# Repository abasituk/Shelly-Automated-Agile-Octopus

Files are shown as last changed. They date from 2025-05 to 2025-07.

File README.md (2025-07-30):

# Shelly-Automated-Agile-Octopus
A system used to automate a Shelly relay to switch on during the cheapest period of the Agile Octopus tariff.

System Diagram (1)

The software requires a Python capable device with WiFi. A Raspberry Pi 4B is used for the build tutorial, with alterantives including cheaper models, such as the Pi Zero 2 W.

## System Functions
- Calculates the cheapest period of electricity prices per day.
- Switches on a Shelly relay through the cloud during the cheapest period, then switches it off outside of that period.
- Hosts a webpage which runs on the local network to display Agile Octopus' half-hourly prices and control the system.

# Hardware List

The relay subsystem may use a Shelly relay when installed into an existing socket or a Shelly Plus plug for portability.

### 1a. BOM for the IoT-based system (Configuration 1).

| Identifier | Component | Quantity | Component Cost [GBP] | Source |
|---|---|---|---|---|
| SBC | Raspberry Pi Zero 2W | 1 | £16.98 | ThePiHut |
| Display | 0.96" OLED Display Module | 1 | £4.00 | ThePiHut |
| SBC Power | Raspberry Pi 12.5W Power Supply | 1 | £7.50 | ThePiHut |
| Smart Relay | Shelly 1PM Gen3 | 1 | £18.50 | ThePiHut |

### 1b. Alternative BOM for the IoT-based system, utilising a smart plug (Configuration 2).

| Identifier | Component | Quantity | Component Cost [GBP] | Source |
|---|---|---|---|---|
| SBC | Raspberry Pi Zero 2W | 1 | £16.98 | ThePiHut |
| Display | 0.96" OLED Display Module | 1 | £4.00 | ThePiHut |
| SBC Power | Raspberry Pi 12.5W Power Supply | 1 | £7.50 | ThePiHut |
| Smart Relay | Shelly Plus Plug | 1 | £18.50 | ThePiHut |

### 3. Additional components used for the control subsystems assembly.

Count|Power/Connectors|
-----|----------------|
1|Rapsberry Pi 15W USB-C Power Supply|
1|14 AWG or 2.5mm<sup>2</sup> Wire|
4|Jumper Wires|
4|M3 x 8 Bolts|
4|M3 Nuts
4|M2 x 6 Bolts|
4|M2 Nuts

If the Shelly Plus plug is be unavailable for purchase, the Shelly relay can be utilised in a customised portable relay subsystem.
### 4. Optional components used to build a portable relay subsystem with the Shelly Relay.

Count|Component
--|--
1|C14 Panel Mount IEC Connector Male
1|IEC C13 Socket to Type G UK Plug Power Cord
1|UK Switched Electrical Socket (2 poles)
6|M3 x 8 length Bolts
6|M3 Nuts
2|M4 Screws
2|M4 Nuts
3|Spade/quick disconnect connectors

# Hardware Build Guide

This section describes how to build two subsystems:
- The Control Subsystem:
  - Consisting of the Raspberry Pi and display, it calculates the cheapest period of energy prices and controls the relay.
- The Relay Subsystem:
  - A circuit which utilises a relay to power an appliance as requested by the control subsystem.

## Control Subsystem Build Guide

### Control Subsystem Printing List

| Count | Model |
|---|---|
| 1 | Pi Zero 2W Enclosure With Screen.stl |
| 2 | Pi Zero 2W Enclosure With Screen Cap.stl |

1. The display is connected to the Raspberry Pi with jumper wires.

|Display|Raspberry Pi Pin|Raspberry Pi Pin Name|
|-|-|-|
SDA|3|GPIO2
SCL|5|GPIO3
VCC|1|3V3
GND|9|GND

2. The Raspberry Pi and display are mounted to the floor of the enclosure with 4 M3 bolts and M2 bolts.



3. The enclosure is folded along its live hinges.

4. Endcaps are press-fitted to both ends.

## Relay Subsystem Build Guide

*Outlines the installation of the Shelly relay into an electrical socket*

1. The Shelly 1PM gen3 is wired according to the diagram:





An animation displays this process, where power is delivered through an IEC connector.

<details>
  <summary>Individual Relay Wiring Images</summary>
  image-description
  image-description
  image-description
  image-description
  image-description
  image-description
  image-description
</details>

# installation guide

## Raspberry Pi Setup

1. Using [Raspberry Pi Imager](https://www.raspberrypi.com/software/), select the utilised Raspberry Pi model, Raspberry Pi OS (64 bit) and your microSD card, then press next

2. On the dialogue that appears, edit the custom OS settings to allow your Pi to connect to your WiFi

3. Type in a username and password for your Pi, then your WiFi name and password

4. Save and apply the settings, then write to your microSD card

5. SSH into the Pi.

## System Installation

1. Download install.sh
```
wget https://raw.githubusercontent.com/abasituk/Shelly-Automated-Agile-Octopus/main/Install.sh
```

2. Give it permission to run
```
chmod +x Install.sh
```

3. Run it with sudo, the script will download the scripts, services and requirements
```
sudo ./Install.sh
```

<br/>

4. After the installation is finished, enable your I2c Interface by first opening your config

  4a. Open your Pi's config
```
sudo raspi-config
```

4b. Open 'Interface Options'

4c. Select 'I2C'

4d. Enable the I2C interface

<br/>
5. Add your Shelly and tariff details to the system's config.ini file
5a. Navigate to where the system was installed

```
cd /home/pi/shelly
```

5b. Open config.ini
```
nano config.ini
```

5c. Add your Shelly and tariff details to the config.ini file without the comments:
```
[Shelly_Variables]                         # Available at https://control.shelly.cloud/
DEVICE_ID = X                                  # device settings -> Device information
SERVER_URI = shelly-X-eu.shelly.cloud          # account settings -> Authorization cloud key (note: not including https://)
AUTH_KEY = X                                   # account settings -> Authorization cloud key

[Tariff_Details]                       # Details for your agile octopus tariff (to interact with the API)
region_code = B                          # Region code for east midlands (e.g. Lincolnshire)
product_code = AGILE-24-10-01            # Your agile octopus tariff's product code
electricity_tariff_type = E-1R           # As Agile Octopus prices change based on wholesale prices, this probably won't need changing
period_size = 1                          # How long you would like your appliance to be switched on (1 period = 0.5 hours)

[Timing_Variables]                     # How quickly the code will loop
INTERVAL = 2                             # Determines how quickly the webgraph updates, increase the value if your Pi is struggling
```

5d. Once the details have been added, press `Ctrl+X`, then `Y`, then `Enter` to save and exit the config.ini file.

<br/>

6. Reload Systemd
```
sudo systemctl daemon-reload
```

7. Restart your services
```
sudo systemctl restart shellycontrol.service webgraph.service
```

<br/>

After these steps, type `http://'Your Pi's IP Address':8080` into a browser on the same WiFi network to access the system's webgraph.

You can also check the status of the services to see if there are any errors:
```
systemctl status shellycontrol.service
```
and
```
systemctl status webgraph.service
```

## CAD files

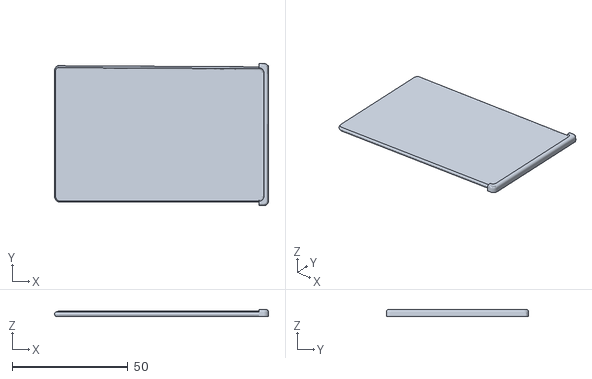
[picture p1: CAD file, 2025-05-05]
Enclosures/Control Subsystem/Raspberry Pi 4B/Raspberry Pi 4B Enclosure Lid 2A.stl
92.5 x 61.5 x 3.00

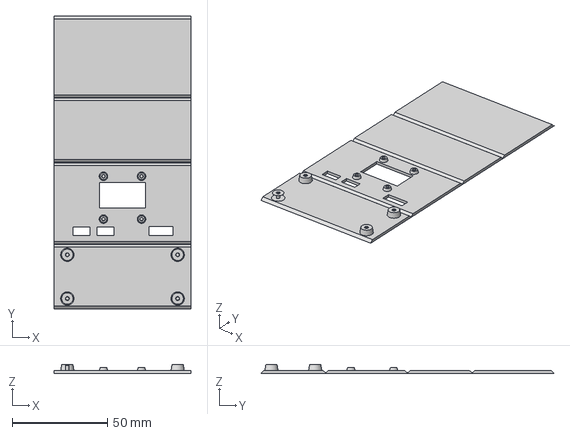
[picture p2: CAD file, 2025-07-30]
Enclosures/Control Subsystem/Raspberry Pi Zero 2W/Pi Zero 2W Enclosure With Screen 14b.step
72.0 x 154.0 x 4.50 mm

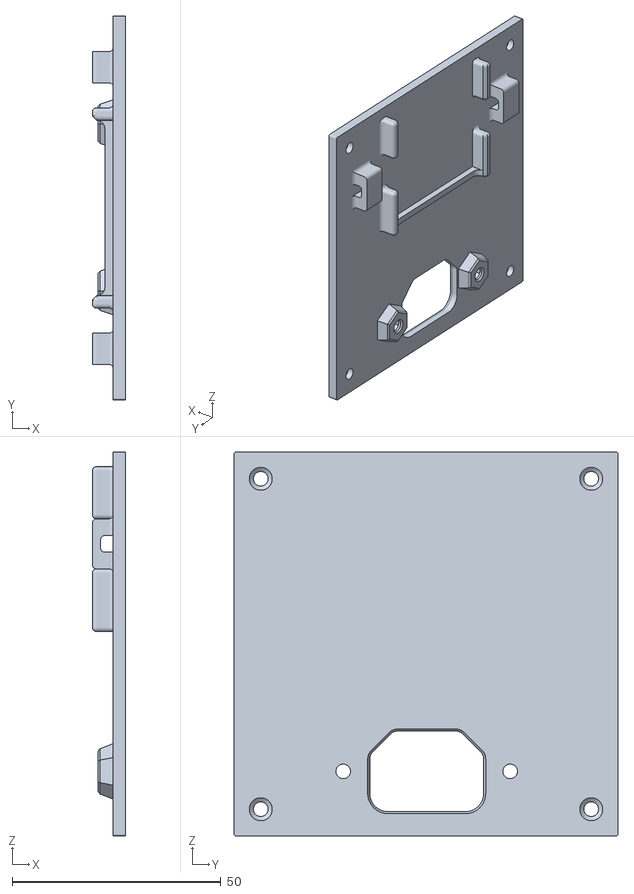
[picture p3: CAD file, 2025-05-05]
Enclosures/Relay Subsystem/Relay Box 2D6 Lid.stl
8.00 x 92.0 x 92.0

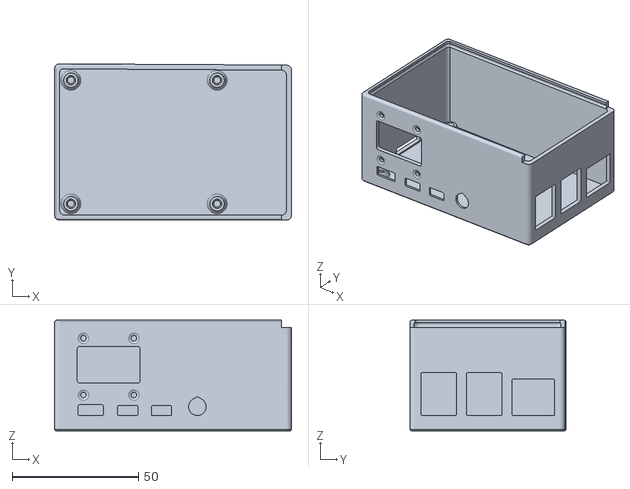
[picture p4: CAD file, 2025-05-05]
Enclosures/Control Subsystem/Raspberry Pi 4B/Raspberry Pi 4B Enclosure 2B.stl
94.0 x 62.0 x 44.0

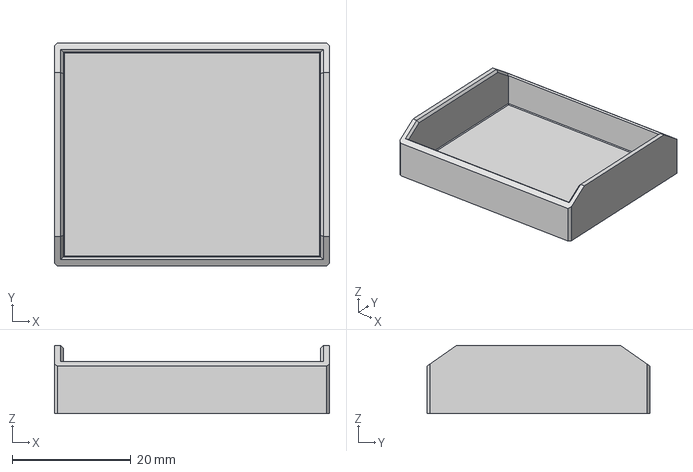
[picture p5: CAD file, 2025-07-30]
Enclosures/Control Subsystem/Raspberry Pi Zero 2W/Pi Zero 2W Enclosure With Screen 14b Cap.step
46.3 x 37.6 x 11.5 mm

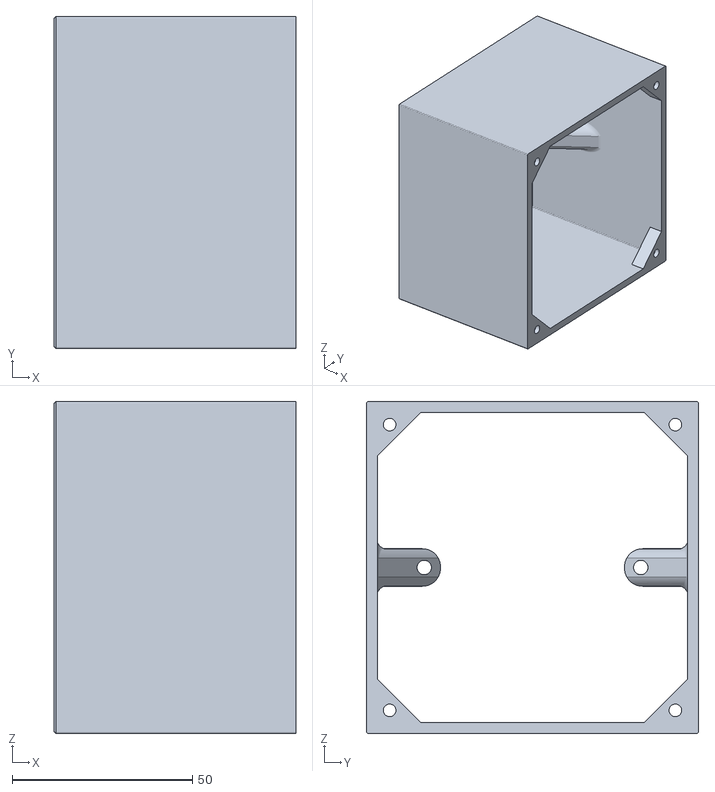
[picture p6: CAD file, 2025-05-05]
Enclosures/Relay Subsystem/Relay Box 2D4.stl
67.0 x 92.0 x 92.0

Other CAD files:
Enclosures/Control Subsystem/Raspberry Pi Zero 2W/Pi Zero 2W Enclosure With Screen 14a.stl
Enclosures/Control Subsystem/Raspberry Pi Zero 2W/Pi Zero 2W Enclosure With Screen 14b Cap.stl

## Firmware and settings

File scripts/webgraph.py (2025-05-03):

import requests
import plotly.graph_objects as go
from plotly.io import to_json
import pandas as pd
from flask import Flask, render_template, request, redirect, url_for, jsonify
from datetime import datetime, timedelta, date, timezone
import time
from threading import Thread
import tzlocal
import os
import configparser

app = Flask(__name__, template_folder=".")

# get the local timezone
local_tz = tzlocal.get_localzone()

# config variables to seperate changeable variables from code ==================================
config = configparser.ConfigParser()
config_file_path = os.path.join(os.path.dirname(__file__), '..', 'config.ini')

try:
    config.read(config_file_path)
except Exception as e:
    print(f"Error reading config.ini file: {e}")
    exit(1)


DEVICE_ID = config.get('Shelly_Variables', 'DEVICE_ID')
SERVER_URI = config.get('Shelly_Variables', 'SERVER_URI')
AUTH_KEY = config.get('Shelly_Variables', 'AUTH_KEY')

region_code = config.get('Tariff_Details', 'region_code')
product_code = config.get('Tariff_Details', 'product_code')
electricity_tariff_type = config.get('Tariff_Details', 'electricity_tariff_type')
period_size = config.getint('Tariff_Details', 'period_size')

INTERVAL = config.getint('Timing_Variables', 'INTERVAL')
# config variables end ========================================================================

automatic_mode = True
start_time_global = None
end_time_global = None


# Optimal Period calc ===============================================================
def retrieve_energy_data_from_api(target_date):
    tomorrow = target_date + timedelta(days=1)
    day_start = datetime.combine(target_date, datetime.min.time(), tzinfo=local_tz).astimezone(timezone.utc).strftime("%Y-%m-%dT%H:%M:%SZ")
    day_end = datetime.combine(tomorrow, datetime.min.time(), tzinfo=local_tz).astimezone(timezone.utc).strftime("%Y-%m-%dT%H:%M:%SZ")

    tariff_code = f"{electricity_tariff_type}-{product_code}-{region_code}"
    base_url = f"https://api.octopus.energy/v1/products/{product_code}/electricity-tariffs/{tariff_code}/standard-unit-rates/"
    params = {"period_from": day_start, "period_to": day_end}
    try:
        response = requests.get(base_url, params=params)
        response.raise_for_status()
        data = response.json()
        results = data.get("results", [])
        if results:
            df = pd.DataFrame(results)
            df["Time Period"] = pd.to_datetime(df["valid_from"]).dt.tz_convert(timezone.utc) # fixed
            df["Price"] = df["value_inc_vat"]
            return df[["Time Period", "Price"]]
        else:
            print(f"Could not find data for {target_date}")
            return None
    except requests.exceptions.RequestException as e:
        print(f"Could not retrieve data from Octopus Energy API: {e}")
        return None

# cycle through the periods to find lowest price
def find_optimal_period(df):
    min_average_price = float("inf")
    optimal_start_index = 0
    
    if df is None or len(df) < period_size:
        return None, None
    for i in range(len(df) - period_size + 1):
        period_average = df["Price"].iloc[i : i + period_size].mean()
        if period_average < min_average_price:
            min_average_price = period_average
            optimal_start_index = i
    return (
        df.iloc[optimal_start_index : optimal_start_index + period_size],
        min_average_price,
    )

# Save the optimal period start and end times, and define what the relay should do during and outside optimal period
def update_optimal_period():
    global start_time_global, end_time_global
    today = date.today()
    df = retrieve_energy_data_from_api(today)

    if df is not None:
        optimal_period_df, average_price = find_optimal_period(
            df.sort_values(by= "Time Period").reset_index(drop=True)
        )
        if optimal_period_df is not None and not optimal_period_df.empty:
            start_time = optimal_period_df["Time Period"].iloc[0]
            end_time = optimal_period_df["Time Period"].iloc[-1] + timedelta(minutes = 30)

            start_time_global = start_time
            end_time_global = end_time

            current_time_utc = datetime.now(timezone.utc)

            if start_time <= current_time_utc < end_time:
                state = switch_relay("on")
                print(f"Relay switched ON for optimal period. Status: {state}")
            else:
                state = switch_relay("off")
                print(f"Relay switched OFF as currently outside optimal period. Status: {state}")
        else:
            print("Could not find optimal period for today")
            switch_relay("off")
            start_time_global = None
            end_time_global = None
    else:
        print("Could not retrieve the energy data for today.")
# ===================================================================================================================================================


# Relay Control =====================================================================================================================================
def relay_status():
    url = f"https://{SERVER_URI}/device/status"
    data = {"id": DEVICE_ID, "auth_key": AUTH_KEY}
    try:
        response = requests.post(url, data = data)
        response.raise_for_status()
        device_data = response.json().get("data", {})
        device_status = device_data.get("device_status", {})
        relay_info = device_status.get("switch:0", {})
        return relay_info.get("output", False)
    except requests.exceptions.RequestException as e:
        print(f"Error checking relay status: {e}")
        return False

# communicate with the shelly relay over cloud
def switch_relay(turn_state):
    url = f"https://{SERVER_URI}/device/relay/control"
    data = {"channel": 0, "turn": turn_state, "id": DEVICE_ID, "auth_key": AUTH_KEY}
    try:
        response = requests.post(url, data=data)
        response.raise_for_status()
        return response.json()
    except requests.exceptions.RequestException as e:
        print(f"Error when trying to control the relay: {e}")
        return {"error": str(e)}


# code to host the webpage locally, which will allow controlling the iot system from PCs, phones etc. on the local network ==================
@app.route("/")
# make a graph for the webpage to visually show the energy prices
def display_graph():
    global start_time_global, end_time_global
    today = date.today()
    df = retrieve_energy_data_from_api(today)

    graph_json = "{}"
    error_message = None

    if df is not None:
        df_sorted = df.sort_values(by="Time Period").reset_index(drop=True)
        optimal_period_df, average_price = find_optimal_period(df_sorted.copy())

        start_time_utc = None
        end_time_utc = None

        if optimal_period_df is not None and not optimal_period_df.empty:
            start_time_utc = optimal_period_df["Time Period"].iloc[0]
            end_time_utc = optimal_period_df["Time Period"].iloc[-1] + timedelta(minutes=30)
            start_time_global = start_time_utc
            end_time_global = end_time_utc
        else:
             if start_time_global and start_time_global.date() == start_time_utc.astimezone(local_tz).date():
                 start_time_global = None
                 end_time_global = None
             average_price = None


        fig = go.Figure()

        df_sorted["Time Period Local"] = df_sorted["Time Period"].dt.tz_convert(local_tz)

        fig.add_trace(
            go.Bar(
                x=df_sorted["Time Period Local"].dt.strftime("%H:%M"),
                y=df_sorted["Price"],
                hovertemplate="Time: %{x}<br>Price: %{y:.2f} p/kWh",
                marker=dict(color=df_sorted["Price"], coloraxis="coloraxis"),
                name="",
            )
        )

        if start_time_utc and end_time_utc and average_price is not None:
            start_time_local_display = start_time_utc.astimezone(local_tz)
            end_time_local_display = end_time_utc.astimezone(local_tz)

            period_duration_minutes = period_size * 30
            if period_duration_minutes >= 60 and period_duration_minutes % 60 == 0:
                duration_text = f"{period_duration_minutes // 60}-Hour"
            else:
                duration_text = f"{period_duration_minutes}-Minute"


            fig.add_annotation(
                x = start_time_local_display.strftime("%H:%M"),
                y = df_sorted["Price"].max() * 1.1 if not df_sorted.empty else 1,
                text = (
                    f"Optimal {duration_text} period: {start_time_local_display.strftime('%H:%M')} - {end_time_local_display.strftime('%H:%M')}<br>"
                    f"Average Price: {average_price:.2f} p/kWh" # 2 decimal places
                ),
                showarrow = False,
                bgcolor = "yellow",
                font = dict(size=16),
            )
        # bug fix 2
        try:
            tz_name = local_tz.key
        except AttributeError:
            tz_name = str(local_tz)

        fig.update_layout(
            xaxis_title=f"Time Period ({tz_name})",
            yaxis_title="Price (p/kWh)",
            coloraxis = dict(colorbar=dict(title="Price (p/kWh)")),
            autosize = True,
        )

        graph_json = to_json(fig)
    else:
        error_message="Could not retrieve energy data."

    # use the webpage
    return render_template(
        "webpage.html",
        graph_json = graph_json,
        interval = INTERVAL,
        automaticMode = automatic_mode,
        error = error_message
    )



@app.route("/status")
# Set what the relay status should be
# 2c 
def get_relay_status():
    global start_time_global, end_time_global
    current_status = relay_status()
    display_relay_status = "ON" if current_status else "OFF"
    auto_mode_status = "ON" if automatic_mode else "OFF"

    current_time_utc = datetime.now(timezone.utc)

    optimal_period_display = "Calculating Optimal Period"
    currently_optimal = "False"

    if start_time_global and end_time_global:
        if start_time_global.astimezone(local_tz).date() == current_time_utc.astimezone(local_tz).date():
            start_time_local_display = start_time_global.astimezone(local_tz)
            end_time_local_display = end_time_global.astimezone(local_tz)
            try:
                tz_name = local_tz.key
            except AttributeError:
                tz_name = str(local_tz)
            optimal_period_display = f"{start_time_local_display.strftime('%H:%M')} - {end_time_local_display.strftime('%H:%M')} ({tz_name})"

            if start_time_global <= current_time_utc < end_time_global:
                 currently_optimal = "True"
            else:
                 currently_optimal = "False"
        else:
             optimal_period_display = "Waiting for today's data"
             currently_optimal = "False"
    else:
        optimal_period_display = "Optimal period data is unavailable"
        currently_optimal = "False"

    return jsonify(
        optimalPeriod=optimal_period_display,
        currentlyOptimal=currently_optimal,
        autoModeStatus=auto_mode_status,
        relayStatus=display_relay_status,
    )

# Webpage buttons ================================
@app.route("/switch_relay", methods=["POST"])
def switch_relay_route():
    turn_state = request.form["turnState"]
    switch_relay(turn_state)
    return redirect(url_for("display_graph"))


@app.route("/toggle_auto_mode", methods=["POST"])
def toggle_auto_mode():
    global automatic_mode
    automatic_mode = not automatic_mode
    return redirect(url_for("display_graph"))


def run_automatic_mode():
    while True:
        if automatic_mode:
            update_optimal_period()
        time.sleep(INTERVAL)
# ===================================================

automatic_thread = Thread(target = run_automatic_mode)
automatic_thread.daemon = True
automatic_thread.start()

if __name__ == "__main__":
    try:
        tz_name = local_tz.key
    except AttributeError:
        tz_name = str(local_tz)
    print(f"Found local timezone: {tz_name}")
    print("Starting Webpage")
    app.run(host = "0.0.0.0", port=8080, debug=False) # run it locally

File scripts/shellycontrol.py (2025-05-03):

import requests
import time
import board
import busio
from PIL import Image, ImageDraw, ImageFont
from adafruit_ssd1306 import SSD1306_I2C
from datetime import datetime

# Variables =======================================================================================
# Typed in camelCase just for ease of distinguishing them in the code
interval = 0.1 # How quick the script is looped
webpageURL = "http://localhost:8080" # this is localhost as the webpage is hosted on the same device

# Set up the OLED screen by setting the pins used
# adafruit_ssd1306 is used because it is compatible with the OLED display
pins = busio.I2C(board.SCL, board.SDA)
oled = SSD1306_I2C(128, 64, pins)

# Set up the display to not have to refresh fully to display something new,
# instead only the pixels that change need to be refreshed, 
# this reduces the screen flashing on and off
previous_display = {
    "optimal_period": "",
    "currently_optimal": "",
    "auto_mode": "",
    "relay_status": ""
}



# Functions =======================================================================================
# Gets information about the 
# optimal period and relay from the webpage so it can be displayed on the webgraph and OLED screen
def get_all_info():
    try:
        response = requests.get(f"{webpageURL}/status")
        response.raise_for_status()
        return response.json()
    except requests.RequestException as e:
        print("Error when retrieving status:", e)
        return None

def update_oled_display(optimal_start, optimal_end, is_currently_optimal, auto_mode_status, relay_status):

    image = Image.new('1', (oled.width, oled.height)) # The display first is set up with an empty image
    draw = ImageDraw.Draw(image)
    font = ImageFont.load_default()

    date = time.strftime("%H:%M   %d/%m/%y")

    # Setting up texts that will be displayed on the OLED, the text changes based on the information,
    new_display = {
        # text name : text then info variables e.g. Auto Mode: true
        "title_text": f"{date}",
        "optimal_period": "Optimal Period:",
        "optimal_period_2": f"{optimal_start} - {optimal_end}",
        "currently_optimal": "Currently Optimal: " + ("True" if is_currently_optimal else "False"),
        "auto_mode": "Auto Mode: " + ("On" if (auto_mode_status == "ON" or auto_mode_status is True) else "Off"),
        "relay_status": "Relay Status: " + ("On" if (relay_status == "ON" or relay_status is True) else "Off")
    }

    # the display is set blank, then the pixels of the text are set on
    draw.rectangle((0, 0, oled.width, oled.height), outline=0, fill=0)
    draw.text((0, 0), new_display["title_text"], font=font, fill=255) #new
    draw.text((0, 14), new_display["optimal_period"], font=font, fill=255) # Starts at 14 because pixels above are yellow for the OLED display
    draw.text((0, 24), new_display["optimal_period_2"], font=font, fill=255)
    draw.text((0, 34), new_display["currently_optimal"], font=font, fill=255)
    draw.text((0, 44), new_display["auto_mode"], font=font, fill=255)
    draw.text((0, 54), new_display["relay_status"], font=font, fill=255)

    oled.image(image)
    oled.show()
    # Now updates the display based on what changed from the previous display to reduce whole screen flashing
    previous_display.update(new_display)



# Makes the code loop based on an interval, as the display's response time is not significantly impacting the responsiveness of the system
while True:
    status = get_all_info()
    if status is not None: # This makes the display update only if the info is available
        optimal_period = status.get("optimalPeriod", "N/A")
        if optimal_period != "Data Unavailable" and " - " in optimal_period:
            optimal_start, optimal_end = optimal_period.split(" - ")
        else:
            optimal_start, optimal_end = "N/A", "N/A"

        # Changes the currently optimal field to bools to be used in update_oled_display()
        currently_optimal_str = status.get("currentlyOptimal", "False")
        is_currently_optimal = True if currently_optimal_str.lower() == "true" else False

        # Get auto mode and relay (Shelly switch) statuses.
        auto_mode_status = status.get("autoModeStatus", "OFF")
        relay_status = status.get("relayStatus", "OFF")

        # Update the OLED display with the latest information.
        update_oled_display(optimal_start, optimal_end, is_currently_optimal, auto_mode_status, relay_status)
    else:
        print("Could not retrieve information from the server") # For logging issues

    time.sleep(interval)

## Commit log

2025-05-05 Rename Enclosures/Relay Box 2D4.stl to Enclosures/Relay Subsystem/Relay Box 2D4.stl
    [Relay Box 2D4.stl]
2025-05-05 Rename Enclosures/Relay Box 2D6 Lid.stl to Enclosures/Relay Subsystem/Relay Enclosure Lid.stl
    [Relay Enclosure Lid.stl]
2025-05-05 Rename Relay Box 2D4.stl to Relay Enclosure.stl
    [Relay Enclosure.stl]
2025-05-05 Create Relay Subsystem
2025-07-30 Rename Pi Zero 2W Enclosure With Screen 14b Cap.stl to Pi Zero 2W Enclosure With Screen 14b Cap.stl
    [Pi Zero 2W Enclosure With Screen 14b Cap.stl]
2025-07-30 added step files for rpiz2w enclosures
    [Pi Zero 2W Enclosure With Screen 14b Cap.step, Pi Zero 2W Enclosure With Screen 14b.step]
